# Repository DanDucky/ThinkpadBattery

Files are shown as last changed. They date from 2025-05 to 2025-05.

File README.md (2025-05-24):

# ThinkpadBattery
Open source Thinkpad battery design

## Fork scope
- Refactor firmware to make use of some of C++'s templating features to make it more readable and better documented.
- Redesign board to use a thermistor and connect directly to the 7 pin connector. Possibly use a battery gas gauge.
- Redesign case to more cleanly incorporate the board and a recommended BMS.
- Provide better documentation on the Thinkpad's specific smart battery protocol instructions.

## What is this?

This is a fully open source laptop battery design. The design uses an attiny85, which can reply to the T420 motherboard's SMBUS requests.

## Setup

### Configurable Constants

- BATTERY_CAPACITY | Your battery capacity in mAH
- V_HIGH | The highest output voltage of your battery, normally 12.6v
- V_LOW | The cutoff for when the battery will stop working, normally around 10.8v

### Creating your own

Parts Needed
- Arduino Uno/Mega  (for programming the attiny85, Mega needs different pin assignment)
- 12v Lithium-Ion battery pack
- 3S Lithium-Ion BMS (it might be possible to use the existing bms if specification is available but communication needs to be implemented)
- Components from schematic
- PCB from schematic

Once you have all these parts, assemble the pcb and attach a BMS to your battery pack. Solder the 12v battery output/input to the large pads on the pcb, then program the attiny85 with the included ino file. The output pins at the bottom of the PCB are a 1-1 mapping of the motherboard pin input.

### Debugging

- The laptop won't supply power to the board unless it detects there's a battery attached, meaning if you plug the board in to the battery without having an external battery to power it, it won't work.

### Libraries

Use the ATTinyCore for compiling. Without it, Wire.h won't work.

## Limitations

### Voltage Reading / Remaining battery

Currently remaining battery %'s aren't exact because I'm assuming there is a linear coorelation between voltage and capacity (Which is wrong). This is probably fixable using a battery gas gauge, I'll have to investiage more.

### MCU Power Consumption

By design, the MCU will always be on as long as a battery is connected to it. This can cause the battery to slowly run out of power if it isn't connected to a laptop. A potential fix could be to implement a low power mode for the attiny, or have a seperate disconnect switch for the battery power on the battery pack itself.

### 3D Printable Case for T420 only

The case for the cells has been completed. The case model and stl files are included in /model

## Future Plans

iam4722202468 - Design and manufacture a PCB with current,voltage and battery capacity measuring capabilities, an easily programmable microcontroller, and a 3s balanced charger

pj1976 - Find a bms that would fit, or try to talk with bq29312pw that was in the original pack

## Credits

iam4722202468 - Initial work, T420 9 cell model

pj1976 - Added support for R50

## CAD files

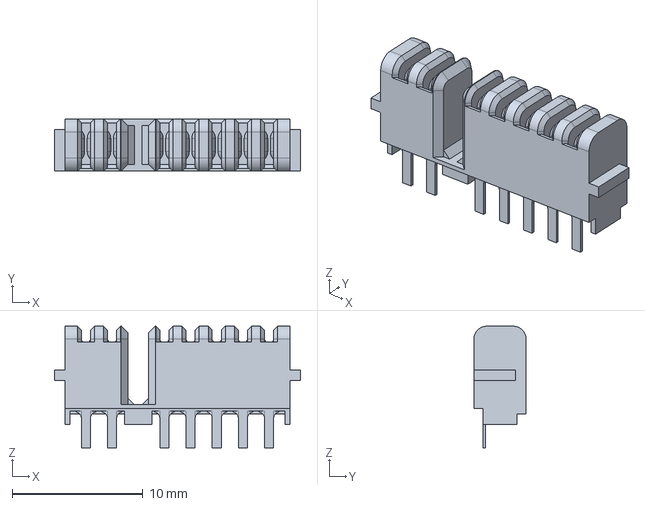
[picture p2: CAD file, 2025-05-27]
board/fuelguage/models/c-2229293-1-b-3d.stp
18.8 x 4.00 x 9.30 mm

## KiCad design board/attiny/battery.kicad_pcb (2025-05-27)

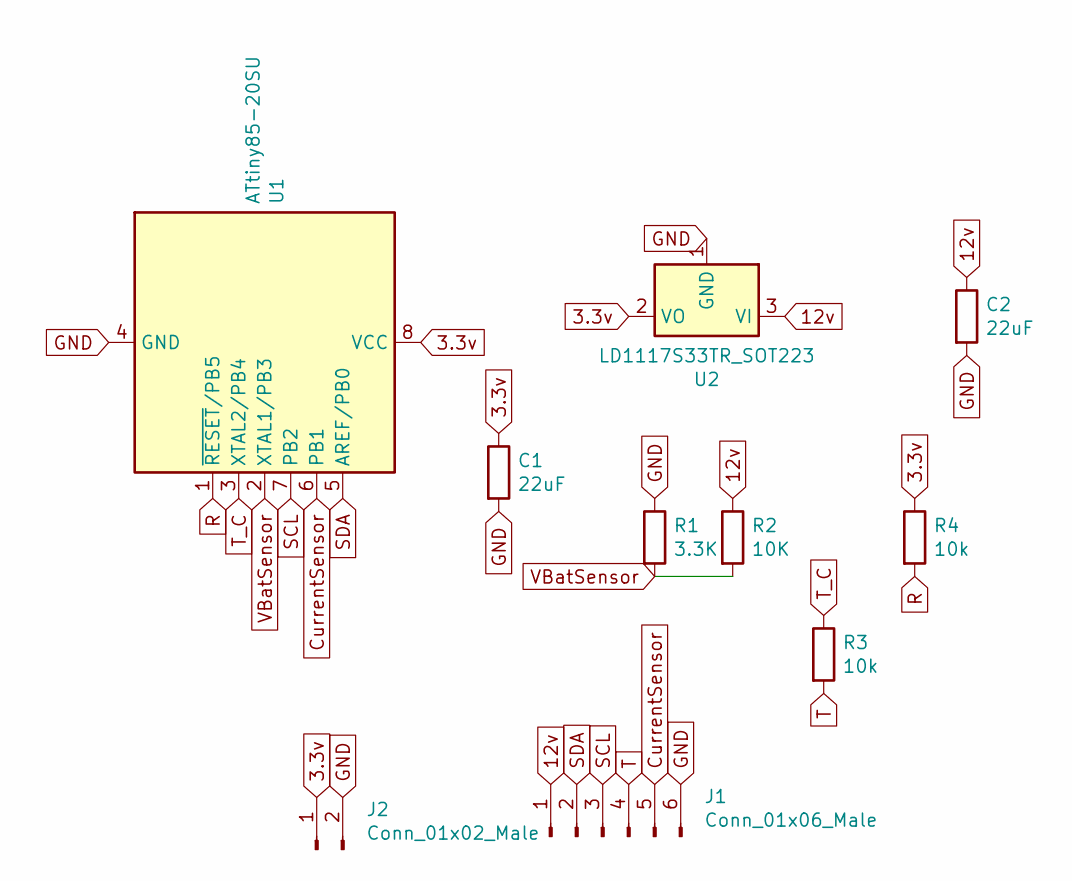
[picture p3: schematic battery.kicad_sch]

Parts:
C1, C2: 22uF; C_0805_2012Metric
J1: Conn_01x06_Male; PinHeader_1x06_P2.54mm_Horizontal
J2: Conn_01x02_Male; PinHeader_1x02_P2.54mm_Vertical
R1: 3.3K; R_0402_1005Metric
R2: 10K; R_0402_1005Metric
R3, R4: 10k; R_0402_1005Metric
U1: ATtiny85-20SU; SOIJ-8_5.3x5.3mm_P1.27mm
U2: LD1117S33TR_SOT223; SOT-223-3_TabPin2

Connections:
3.3v: C1.1, J2.1, R4.1, U1.8 (VCC), U2.2 (VO)
12v: C2.1, J1.1, R2.1, U2.3 (VI)
CurrentSensor: J1.5, U1.6 (PB1)
GND: C1.2, C2.2, J1.6, J2.2, R1.1, U1.4 (GND), U2.1 (GND)
R: R4.2, U1.1 (~RESET/PB5)
SCL: J1.3, U1.7 (PB2)
SDA: J1.2, U1.5 (AREF/PB0)
T: J1.4, R3.2
T_C: R3.1, U1.3 (XTAL2/PB4)
VBatSensor: R1.2, R2.2, U1.2 (XTAL1/PB3)

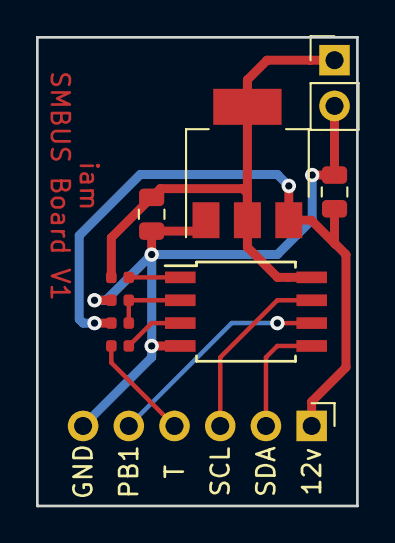
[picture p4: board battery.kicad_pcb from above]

Board: 2 copper layers, 17.8 x 26.0 mm, 10 parts (0 on the bottom side), 10 nets.

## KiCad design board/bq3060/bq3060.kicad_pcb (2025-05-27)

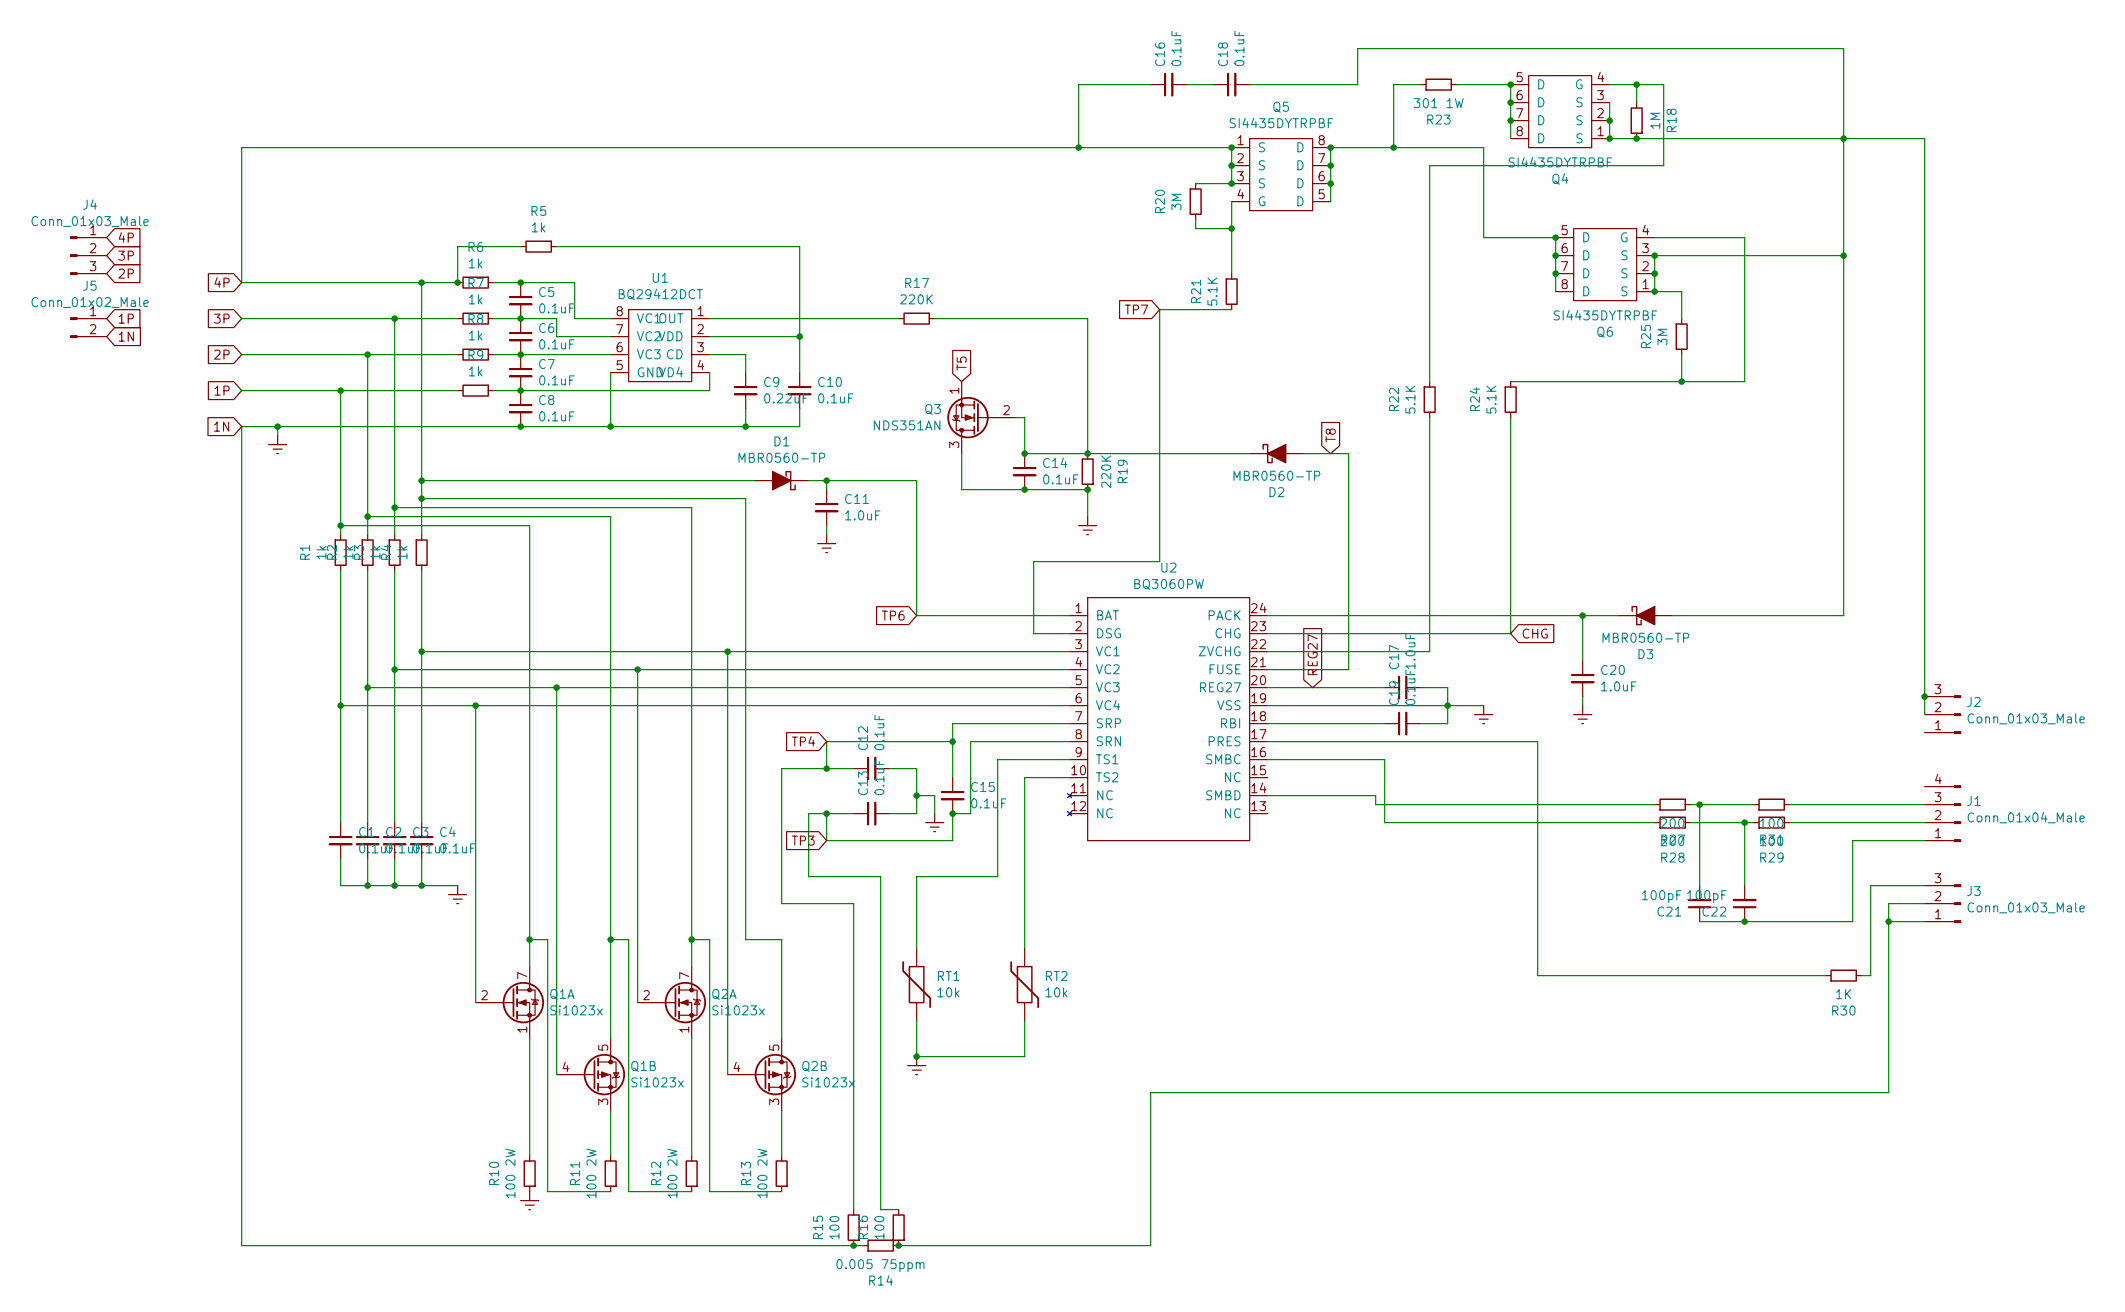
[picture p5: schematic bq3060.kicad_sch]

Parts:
C1, C2, C3, C4, C5, C6, C7, C8, C10, C12, C13, C14, C15, C16, C18, C19: 0.1uF; C_0805_2012Metric_Pad1.15x1.40mm_HandSolder
C9: 0.22uF; C_0805_2012Metric_Pad1.15x1.40mm_HandSolder
C11, C17, C20: 1.0uF; C_0805_2012Metric_Pad1.15x1.40mm_HandSolder
C21, C22: 100pF; C_0805_2012Metric_Pad1.15x1.40mm_HandSolder
D1, D2, D3: MBR0560-TP; D_SOD-123
J1: Conn_01x04_Male; PinHeader_1x04_P2.54mm_Horizontal
J2, J3: Conn_01x03_Male; PinHeader_1x03_P2.54mm_Vertical
J4: Conn_01x03_Male; SolderWirePad_1x03_P5.715mm_Drill2mm
J5: Conn_01x02_Male; SolderWirePad_1x02_P7.62mm_Drill2mm
Q1, Q2: Si1023x; SOIC-8_3.9x4.9mm_P1.27mm
Q3: NDS351AN; SOT-23
Q4, Q5, Q6: SI4435DYTRPBF; SOIC-8_3.9x4.9mm_P1.27mm
R1, R2, R3, R4, R5, R6, R7, R8, R9: 1k; R_0805_2012Metric_Pad1.15x1.40mm_HandSolder
R10, R11, R12, R13: 100 2W; R_2512_6332Metric_Pad1.52x3.35mm_HandSolder
R14: 0.005 75ppm; R_2512_6332Metric_Pad1.52x3.35mm_HandSolder
R15, R16, R29, R31: 100; R_0805_2012Metric_Pad1.15x1.40mm_HandSolder
R17, R19: 220K; R_0805_2012Metric_Pad1.15x1.40mm_HandSolder
R18: 1M; R_0805_2012Metric_Pad1.15x1.40mm_HandSolder
R20, R25: 3M; R_0805_2012Metric_Pad1.15x1.40mm_HandSolder
R21, R22, R24: 5.1K; R_0805_2012Metric_Pad1.15x1.40mm_HandSolder
R23: 301 1W; R_2512_6332Metric_Pad1.52x3.35mm_HandSolder
R27, R28: 200; R_0805_2012Metric_Pad1.15x1.40mm_HandSolder
R30: 1K; R_0805_2012Metric_Pad1.15x1.40mm_HandSolder
RT1, RT2: 10k; R_0805_2012Metric_Pad1.15x1.40mm_HandSolder
U1: BQ29412DCT; SN74LVC2G241_DCT_8
U2: BQ3060PW; TSSOP-24_4.4x7.8mm_P0.65mm

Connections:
1N: C1.2, C2.2, C3.2, C4.2, C8.2, C9.2, C10.2, C11.2, C12.2, C13.2, C14.2, C17.2, C19.2, C20.2, J5.2, Q3.3 (D), R10.1, R14.1, R15.1, R19.1, RT1.2, RT2.2, U1.5 (GND), U2.19 (VSS)
1P: J5.1, Q1.7 (D1), Q1.8 (D1), R1.1, R9.2, R11.1
2P: J4.3, Q1.5 (D2), Q1.6 (D2), R2.1, R8.2, R12.1
3P: J4.2, Q2.7 (D1), Q2.8 (D1), R3.1, R7.2, R13.1
4P: C16.1, D1.2 (A), J4.1, Q2.5 (D2), Q2.6 (D2), Q5.1 (S), Q5.2 (S), Q5.3 (S), R4.1, R5.2, R6.2, R20.1
CHG: R24.2, U2.23 (CHG)
unnamed: C1.1, Q1.2 (G1), R1.2, U2.6 (VC4)
unnamed: C2.1, Q1.4 (G2), R2.2, U2.5 (VC3)
unnamed: C3.1, Q2.2 (G1), R3.2, U2.4 (VC2)
unnamed: C4.1, Q2.4 (G2), R4.2, U2.3 (VC1)
unnamed: C5.1, R6.1, U1.8 (VC1)
unnamed: C5.2, C6.1, R7.1, U1.7 (VC2)
unnamed: C6.2, C7.1, R8.1, U1.6 (VC3)
unnamed: C7.2, C8.1, R9.1, U1.4 (VD4)
unnamed: C9.1, U1.3 (CD)
unnamed: C10.1, R5.1, U1.2 (VDD)
unnamed: C14.1, D2.1 (K), Q3.2 (G), R17.1, R19.2
unnamed: C16.2, C18.1
unnamed: C18.2, D3.2 (A), J2.2, J2.3, Q4.1 (S), Q4.2 (S), Q4.3 (S), Q6.1 (S), Q6.2 (S), Q6.3 (S), R18.1, R25.1
unnamed: C19.1, U2.18 (RBI)
unnamed: C20.1, D3.1 (K), U2.24 (PACK)
unnamed: C21.1, C22.1, J1.1
unnamed: C21.2, R27.2, R31.1
unnamed: C22.2, R28.2, R29.1
unnamed: J1.2, R29.2
unnamed: J1.3, R31.2
unnamed: J3.1, J3.2, R14.2, R16.1
unnamed: J3.3, R30.2
unnamed: Q1.1 (S1), R10.2
unnamed: Q1.3 (S2), R11.2
unnamed: Q2.1 (S1), R12.2
unnamed: Q2.3 (S2), R13.2
unnamed: Q4.4 (G), R18.2, R22.1
unnamed: Q4.5 (D), Q4.6 (D), Q4.7 (D), Q4.8 (D), R23.2
unnamed: Q5.4 (G), R20.2, R21.1
unnamed: Q5.5 (D), Q5.6 (D), Q5.7 (D), Q5.8 (D), Q6.5 (D), Q6.6 (D), Q6.7 (D), Q6.8 (D), R23.1
unnamed: Q6.4 (G), R24.1, R25.2
unnamed: R17.2, U1.1 (OUT)
unnamed: R22.2, U2.22 (ZVCHG)
unnamed: R27.1, U2.14 (SMBD)
unnamed: R28.1, U2.16 (SMBC)
unnamed: R30.1, U2.17 (PRES)
unnamed: RT1.1, U2.9 (TS1)
unnamed: RT2.1, U2.10 (TS2)
REG27: C17.1, U2.20 (REG27)
T5: Q3.1 (S)
T8: D2.2 (A), U2.21 (FUSE)
TP3: C13.1, C15.2, R16.2, U2.8 (SRN)
TP4: C12.1, C15.1, R15.2, U2.7 (SRP)
TP6: C11.1, D1.1 (K), U2.1 (BAT)
TP7: R21.2, U2.2 (DSG)

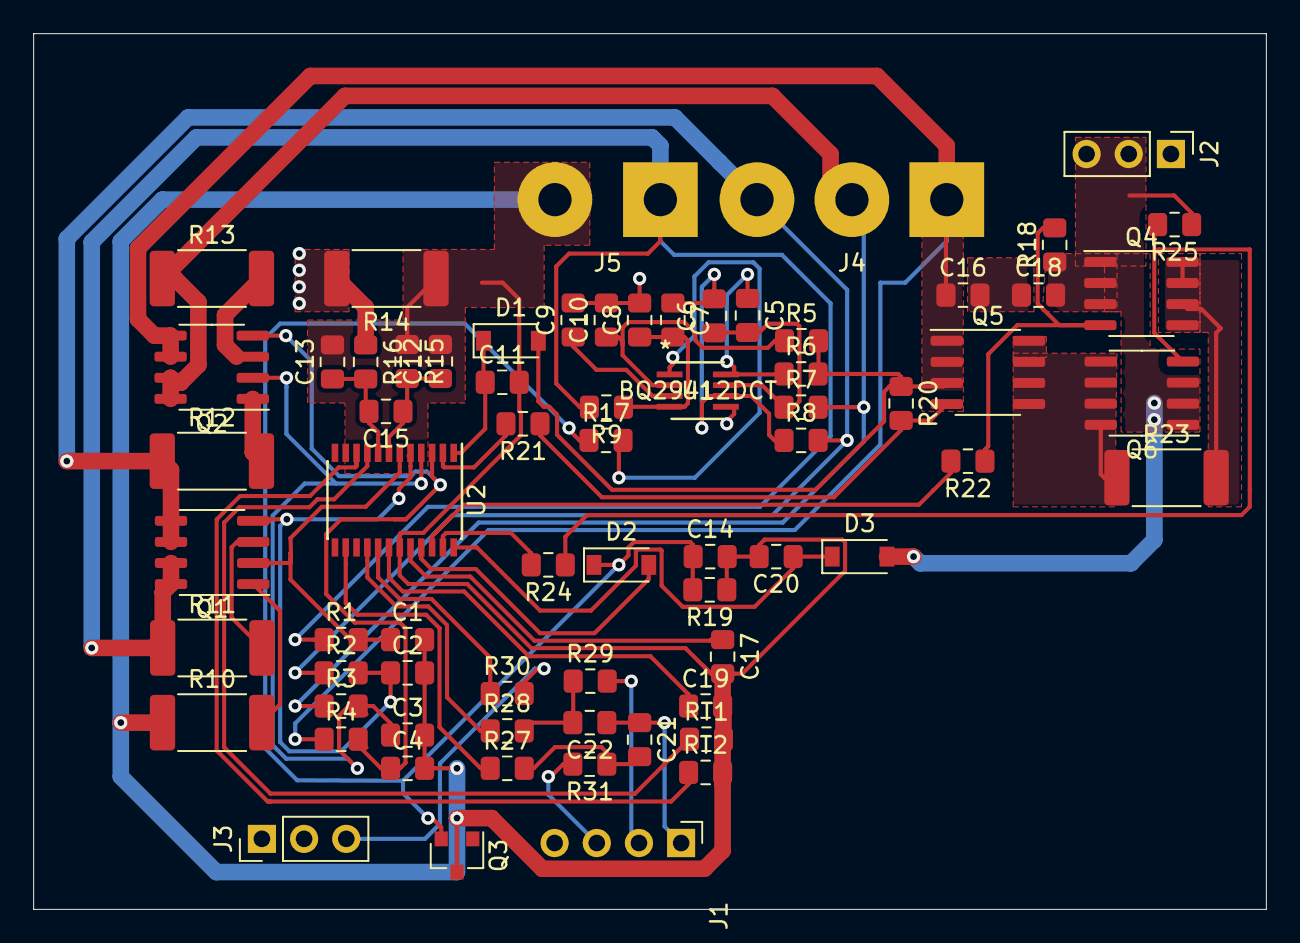
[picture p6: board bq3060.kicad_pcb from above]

Board: 2 copper layers, 74.2 x 52.8 mm, 70 parts (0 on the bottom side), 50 nets.

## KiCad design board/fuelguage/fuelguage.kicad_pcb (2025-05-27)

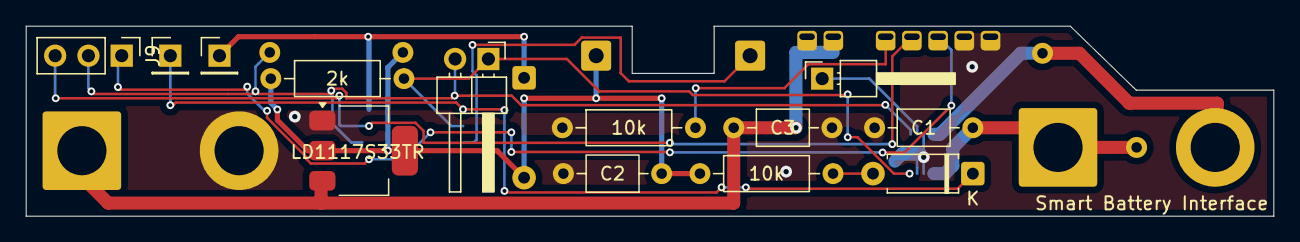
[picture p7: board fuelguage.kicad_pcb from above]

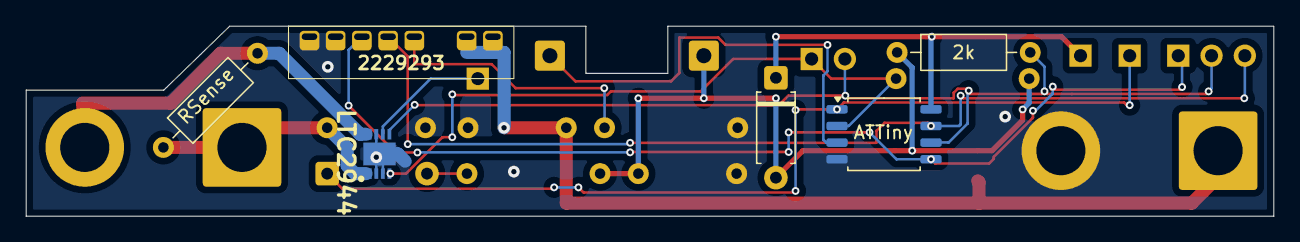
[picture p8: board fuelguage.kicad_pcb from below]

Board: 2 copper layers, 95.2 x 14.5 mm, 23 parts (6 on the bottom side), 15 nets.

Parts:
2k, 2k#2: 2k; R_Axial_DIN0207_L6.3mm_D2.5mm_P10.16mm_Horizontal
10k, 10k#2: 10k; R_Axial_DIN0207_L6.3mm_D2.5mm_P10.16mm_Horizontal
2229293: 2229293-1_vertical
ATTiny: ATtiny85-20SU; SOIC-8_5.3x5.3mm_P1.27mm
C1: 0.001; C_Axial_L3.8mm_D2.6mm_P7.50mm_Horizontal
C2, C3: 0.022; C_Axial_L3.8mm_D2.6mm_P7.50mm_Horizontal
D1, D2: 1N4007; D_A-405_P7.62mm_Horizontal
J1, J12: Conn_01x02_Socket; SolderWire-4sqmm_1x02_P12mm_D3mm_OD6mm
J4: Conn_01x02_Pin; PinHeader_1x02_P2.54mm_Horizontal
J6: Conn_01x01_Pin; PinHeader_1x01_P2.54mm_Horizontal
J7, J11: Conn_01x01_Pin; PinHeader_1x01_P2.54mm_Vertical
J8, J10: Conn_01x01_Socket; SolderWire-0.5sqmm_1x01_D0.9mm_OD2.3mm
J9: Conn_01x03_Pin; PinHeader_1x03_P2.54mm_Vertical
LD1117S33TR: LD1117S33TR_SOT223; SOT-223-3_TabPin2
LTC2944: LTC2944IDD#PBF; LTC2944
RSense: 50m; R_Axial_DIN0207_L6.3mm_D2.5mm_P10.16mm_Horizontal

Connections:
3.3v: 2k.1, 2k#2.1, 10k#2.1, C2.1, D2.2 (A), J10.1, LD1117S33TR.2 (VO)
12v: 2229293.0 (+), C3.1, J1.1, LD1117S33TR.3 (VI)
GND: 10k.1, 2229293.6 (-), ATTiny.4 (GND), C1.1, C2.2, C3.2, J1.2, LD1117S33TR.1 (GND), LTC2944.2 (GND_1), LTC2944.3 (GND_2), LTC2944.7 (GND_3), LTC2944.9 (EP)
unnamed: 10k#2.2, D1.2 (A)
unnamed: ATTiny.1 (~RESET/PB5), D1.1 (K), J7.1
unnamed: ATTiny.8 (VCC), D2.1 (K), J11.1
unnamed: 2k.2, ATTiny.2 (XTAL1/PB3), J4.1, LTC2944.4 (SCL)
unnamed: 2k#2.2, ATTiny.6 (PB1), J4.2, J9.2, LTC2944.5 (SDA)
unnamed: C1.2, J12.1, LTC2944.1 (SENSE+), RSense.1
unnamed: J12.2, LTC2944.8 (SENSE-), RSense.2
unnamed: J6.1, LTC2944.6 (~ALCC)
unnamed: ATTiny.3 (XTAL2/PB4), J8.1
unnamed: 2229293.3 (SDA), ATTiny.5 (AREF/PB0), J9.1
unnamed: 2229293.2 (SCL), ATTiny.7 (PB2), J9.3
unnamed: 10k.2, 2229293.1 (thermistor)

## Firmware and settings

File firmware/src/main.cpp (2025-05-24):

#include <Arduino.h>
#include <Wire.h>

// First 4 chars are cut off
#define BATTERY_MODEL "LNV-Version 2"
#define BATTERY_VENDOR "HACKED"
#define CHARGE_VOLTAGE 12600
#define BATTERY_VOLTAGE 10800
#define SERIAL 420

#define V_HIGH 12.1

// 20% above where the battery actually dies. This is because on load my T420 can pull the voltage down 20%.
// If you're using a non-modified T420 you can probably use 10.2-10.3 here and get 10% more battery life.
#define V_LOW 10.52

// mAh, uses BATTERY_VOLTAGE when calculating Wh
#define BATTERY_CAPACITY 15000
#define BATTERY_CAPACITY_DESIGN 15000

byte command;

// 0 - Charging
// 1 - Battery Powered
int mode = 1;

void splitNum(int num, int *upper, int *lower) {
    *lower = (num & 0xff00) >> 8;
    *upper = num & 0x00ff;
}

bool needsLength(int type) {
    return type == 0x20 ||
           type == 0x21 ||
           type == 0x22 ||
           type == 0x23 ||
           type == 0x30 ||
           type == 0x3C ||
           type == 0x37 ||
           type == 0x2F;
}

void iterateCRC(bool CRC[8], int currentByte) {
    for (int y = 0; y < 8; ++y) {
        bool currentBit = (currentByte >> (7 - y)) & 0x01;
        bool invert = currentBit ^ CRC[7];

        CRC[7] = CRC[6];
        CRC[6] = CRC[5];
        CRC[5] = CRC[4];
        CRC[4] = CRC[3];
        CRC[3] = CRC[2];
        CRC[2] = CRC[1] ^ invert;
        CRC[1] = CRC[0] ^ invert;
        CRC[0] = invert;
    }
}

// CRC function, used as a checksum for the data send to the laptop
int genCRC(byte *arr, int len, int replyTo) {
    bool CRC[8];
    bool addLength = needsLength(replyTo);

    for (int i = 0; i < 8; ++i) CRC[i] = 0;

    iterateCRC(CRC, 22);
    iterateCRC(CRC, replyTo);
    iterateCRC(CRC, 23);

    if (addLength)
        iterateCRC(CRC, len);

    for (int x = 0; x < len; ++x) {
        int currentByte = arr[x];
        iterateCRC(CRC, currentByte);
    }

    int final = 0;

    for (int x = 0; x < 8; ++x)
        final += (0x01 << x) * CRC[x];

    // Serial.println(final);
    return final;
}

// Function signature for callbacks
// Takes byte array for a buffer and returns the number of bytes written to it
typedef byte (*smbusCallback)(byte *);

byte reply0x00(byte *buff) {
    buff[0] = 24;
    buff[1] = 0;
    return 2;
}

byte reply0x01(byte *buff) {
    buff[0] = 44;
    buff[1] = 1;
    return 2;
}

byte reply0x02(byte *buff) {
    buff[0] = 30;
    buff[1] = 0;
    return 2;
}

byte reply0x03(byte *buff) {
    buff[0] = 132;
    buff[1] = 128;

    return 2;
}

byte reply0x04(byte *buff) {
    buff[0] = 0;
    buff[1] = 0;
    return 2;
}

// 0x05

byte reply0x06(byte *buff) {
    buff[0] = 100;
    buff[1] = 0;

    return 2;
}

// 0x07

byte reply0x08(byte *buff) {
    buff[0] = 137;
    buff[1] = 11;

    return 2;
}

byte reply0x09(byte *buff) {
    int lower, higher;

    // Values of the resistors used in the voltage divider
    float r1 = 9.89;
    float r2 = 3.39;

    // Read the voltage divider input on analog pin that has a range of 3.33v to 0v, and output a number from 0 to 1024
    float voltageIn = analogRead(3) * (3.33 / 1024.0);
    float vin = voltageIn / (r2 / (r1 + r2));
    int Vinoff = vin * 1000;

    if (vin < 0)
        vin = 0;

    splitNum(Vinoff, &lower, &higher);
    buff[0] = lower;
    buff[1] = higher;

    return 2;
}

byte reply0x0a(byte *buff) {
    if (mode == 0) {
        buff[0] = 0;
        buff[1] = 0;
    } else {
        buff[0] = 0xF8;
        buff[1] = 0xFC;
    }

    return 2;
}

byte reply0x0b(byte *buff) {
    if (mode == 0) {
        buff[0] = 0;
        buff[1] = 0;
    } else {
        buff[0] = 0xF6;
        buff[1] = 0xFC;
    }

    return 2;
}

byte reply0x0c(byte *buff) {
    buff[0] = 0x00;
    buff[1] = 0x00;

    return 2;
}

// Relative state of charge
byte reply0x0d(byte *buff) {
    buff[0] = 0x5b;
    buff[1] = 0x00;

    return 2;
}

// 0x0e

byte reply0x0f(byte *buff) {
    int lower, higher;

    float r1 = 9.89;
    float r2 = 3.39;

    float sensorLow = V_LOW * (r2 / (r1 + r2));
    float sensorHigh = V_HIGH * (r2 / (r1 + r2));

    // Assume linear voltage -> battery capacity coorelation (this isn't perfect)
    // y = mx + b
    float m = 1 / (sensorHigh - sensorLow);
    float b = -sensorLow * m;

    float voltageIn = analogRead(3) * (3.33 / 1024.0);
    int batteryVoltage = (m * voltageIn + b) * BATTERY_CAPACITY;

    if (batteryVoltage < 0)
        batteryVoltage = 0;

    splitNum(batteryVoltage, &lower, &higher);
    buff[0] = lower;
    buff[1] = higher;

    return 2;
}

byte reply0x10(byte *buff) {
    int lower, higher;

    splitNum(BATTERY_CAPACITY, &lower, &higher);
    buff[0] = lower;
    buff[1] = higher;

    return 2;
}

// Run time to empty
byte reply0x11(byte *buff) {
    buff[0] = 60;
    buff[1] = 0x00;

    return 2;
}

byte reply0x12(byte *buff) {
    buff[0] = 255;
    buff[1] = 255;

    return 2;
}

byte reply0x13(byte *buff) {
    buff[0] = 255;
    buff[1] = 255;

    return 2;
}

// 0x14-0x16

byte reply0x17(byte *buff) {
    buff[0] = 20;
    buff[1] = 5;

    return 2;
}

byte reply0x14(byte *buff) {
    buff[0] = 228;
    buff[1] = 12;

    return 2;
}

byte reply0x15(byte *buff) {
    int lower, higher;

    splitNum(CHARGE_VOLTAGE, &lower, &higher);
    buff[0] = lower;
    buff[1] = higher;

    return 2;
}

byte reply0x16(byte *buff) {
    buff[0] = 224;
    buff[1] = 192;

    return 2;
}

// 0x17

byte reply0x18(byte *buff) {
    int lower, higher;

    splitNum(BATTERY_CAPACITY_DESIGN, &lower, &higher);
    buff[0] = lower;
    buff[1] = higher;

    return 2;
}

byte reply0x19(byte *buff) {
    int lower, higher;

    splitNum(BATTERY_VOLTAGE, &lower, &higher);
    buff[0] = lower;
    buff[1] = higher;

    return 2;
}

byte reply0x1a(byte *buff) {
    buff[0] = 49;
    return 1;
}

byte reply0x1b(byte *buff) {
    buff[0] = 156;
    buff[1] = 61;
    return 2;
}

byte reply0x1c(byte *buff) {
    int lower, higher;

    splitNum(SERIAL, &lower, &higher);
    buff[0] = lower;
    buff[1] = higher;

    return 2;
}

// 0x1d-0x1f

byte reply0x20(byte *buff) {
    auto battery_vendor = BATTERY_VENDOR;

    for (int x = 0; x < strlen(battery_vendor); ++x) {
        buff[x] = battery_vendor[x];
    }

    const int end = strlen(battery_vendor);

    buff[end + 0] = 0;
    buff[end + 1] = 49;
    buff[end + 2] = 49;

    return strlen(battery_vendor) + 3;
}

byte reply0x21(byte *buff) {
    char *battery_model = BATTERY_MODEL;

    for (int x = 0; x < strlen(battery_model); ++x) {
        buff[x] = battery_model[x];
    }

    return strlen(battery_model);
}

// Device chemistry
byte reply0x22(byte *buff) {
    buff[0] = 76;
    buff[1] = 73;
    buff[2] = 79;
    buff[3] = 78;

    return 4;
}

byte reply0x23(byte *buff) {
    buff[0] = 0x42;
    buff[1] = 0x0a;
    buff[2] = 0x05;
    buff[3] = 0x12;
    buff[4] = 0x86;
    buff[5] = 0x0f;
    buff[6] = 0x86;
    buff[7] = 0x0f;
    buff[8] = 0x86;
    buff[9] = 0x0f;
    buff[10] = 0x86;
    buff[11] = 0x0f;

    return 12;
}

// 0x24-0x2e

// ?
byte reply0x2f(byte *buff) {
    buff[0] = 49;
    buff[1] = 90;
    buff[2] = 74;
    buff[3] = 51;
    buff[4] = 74;
    buff[5] = 49;
    buff[6] = 49;
    buff[7] = 77;
    buff[8] = 49;
    buff[9] = 50;
    buff[10] = 88;

    return 11;
}

byte reply0x30(byte *buff) {
    buff[0] = 112;
    buff[1] = 156;
    buff[2] = 191;
    buff[3] = 25;
    buff[4] = 132;
    buff[5] = 74;
    buff[6] = 151;
    buff[7] = 0;
    buff[8] = 11;
    buff[9] = 0;

    return 10;
}

// 0x31-0x34

// ?
byte reply0x35(byte *buff) {
    buff[0] = 64;
    buff[1] = 0;

    return 2;
}

// 0x36

// ?
byte reply0x37(byte *buff) {
    buff[0] = 4;
    buff[1] = 0;
    buff[2] = 61;
    buff[3] = 94;
    buff[4] = 97;
    buff[5] = 1;
    buff[6] = 64;
    buff[7] = 1;

    return 8;
}

// 0x38-0x3a

byte reply0x3b(byte *buff) {
    buff[0] = 135;
    buff[1] = 11;

    return 2;
}

byte reply0x3c(byte *buff) {
    buff[0] = 76;
    buff[1] = 101;
    buff[2] = 110;
    buff[3] = 111;
    buff[4] = 118;
    buff[5] = 111;
    buff[6] = 32;
    buff[7] = 74;
    buff[8] = 97;
    buff[9] = 112;
    buff[10] = 97;
    buff[11] = 110;
    buff[12] = 145;
    buff[13] = 46;
    buff[14] = 93;
    buff[15] = 230;

    return 16;
}

byte reply0x3d(byte *buff) {
    buff[0] = 136;
    buff[1] = 11;

    return 2;
}

byte reply0x3e(byte *buff) {
    buff[0] = 1;
    buff[1] = 0;

    return 2;
}

byte reply0x3f(byte *buff) {
    buff[0] = 47;
    buff[1] = 79;

    return 2;
}


// Store a mapping of bytes to functions
// index 0 is used to reply to byte command 0, index 1 is used to reply to byte command 1, etc.
// NULL values are functions that are commands that are not used or have not been implemented
// See https://www.nxp.com/docs/en/application-note/AN4471.pdf for more information about what each command does

// Each of these functions will write to the global buffer and return the amount of bytes written
byte (*funMap[])(byte *) = {
    reply0x00,
    reply0x01,
    reply0x02,
    reply0x03,
    reply0x04,
    nullptr,
    reply0x06,
    nullptr,
    reply0x08,
    reply0x09,
    reply0x0a,
    reply0x0b,
    reply0x0c,
    reply0x0d,
    nullptr,
    reply0x0f,
    reply0x10,
    reply0x11,
    reply0x12,
    reply0x13,
    reply0x14,
    reply0x15,
    reply0x16,
    reply0x17,
    reply0x18,
    reply0x19,
    reply0x1a,
    reply0x1b,
    reply0x1c,
    nullptr,
    nullptr,
    nullptr,
    reply0x20,
    reply0x21,
    reply0x22,
    reply0x23,
    nullptr,
    nullptr,
    nullptr,
    nullptr,
    nullptr,
    nullptr,
    nullptr,
    nullptr,
    nullptr,
    nullptr,
    nullptr,
    reply0x2f,
    reply0x30,
    nullptr,
    nullptr,
    nullptr,
    nullptr,
    reply0x35,
    nullptr,
    reply0x37,
    nullptr,
    nullptr,
    nullptr,
    reply0x3b,
    reply0x3c,
    reply0x3d,
    reply0x3e,
    reply0x3f
};

// Used to store replies to commands
byte buffGlobal[60];

// Read command send from laptop
void receiveEvent(const int howMany) {
    // Set command
    command = Wire.read();

    // Ignore bytes other than the first one. No commands currently require more than one byte
    for (int x = 0; x < howMany - 1; x++) {
        Wire.read();
    }
}

// Write information and send it to laptop
void requestEvent() {
    // Look up the callback associated with the current command, NULL if no match is found
    const smbusCallback callback = funMap[command];

    // No matching callback was found, return without further processing
    if (callback == nullptr)
        return;

    // Call matching callback, which writes to the global buffer and returns the amount of bytes written
    const int len = callback(buffGlobal);

    // Some commands require their length to be added. See needsLength function for a list of these commands
    // This length command is sent first, before all the data
    if (needsLength(command))
        Wire.write(len);

    // Write all bytes from the buffer
    for (int y = 0; y < len; ++y) {
        Wire.write(buffGlobal[y]);
    }

    // Generate and write the CRC. This is a checksum used to ensure communication works as intended
    Wire.write(genCRC(buffGlobal, len, command));
}

void setup() {
    pinMode(PB3, INPUT);

    pinMode(PB4, OUTPUT);
    digitalWrite(PB4, LOW);

    command = 0;

    Wire.begin(0x0B);
    Wire.onReceive(receiveEvent);
    Wire.onRequest(requestEvent);
}

void loop() {
    delay(1);
}

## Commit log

2025-05-24 quick reformat
    [battery.kicad_pcb, battery.sch, bq3060.kicad_pcb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]
2025-05-27 dev board
    [battery.kicad_pcb, battery.kicad_sch, bq3060.kicad_pcb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]

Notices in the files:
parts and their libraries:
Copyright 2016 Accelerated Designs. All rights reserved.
